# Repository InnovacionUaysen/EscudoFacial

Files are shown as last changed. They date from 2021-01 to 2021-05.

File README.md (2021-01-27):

# EscudoFacial
Escudo facial desarrollado por FabLab de la Universidad de Aysén
La informacion contenida en el manual adjunto debe respetarse para una correcta fabricación del escudo facial validado por el laboratorio Lictex de la Universidad de Santiago de Chile.
Este escudo facial esta registrado bajo las licencias Creative commons, 
Creative Commons Licence
EscudoFacial Uaysen by Universidad de Aysén is licensed under a Creative Commons Attribution-NoDerivatives 4.0 International License.
Based on a work at https://github.com/InnovacionUaysen/EscudoFacial.
<br /><span xmlns:dct="http://purl.org/dc/terms/" property="dct:title">EscudoFacial Uaysen</span> by <a xmlns:cc="http://creativecommons.org/ns#" href="https://github.com/InnovacionUaysen" property="cc:attributionName" rel="cc:attributionURL">Universidad de Aysén</a> is licensed under a <a rel="license" href="http://creativecommons.org/licenses/by-nd/4.0/">Creative Commons Attribution-NoDerivatives 4.0 International License</a>.<br />Based on a work at <a xmlns:dct="http://purl.org/dc/terms/" href="https://github.com/InnovacionUaysen/EscudoFacial" rel="dct:source">https://github.com/InnovacionUaysen/EscudoFacial</a>.

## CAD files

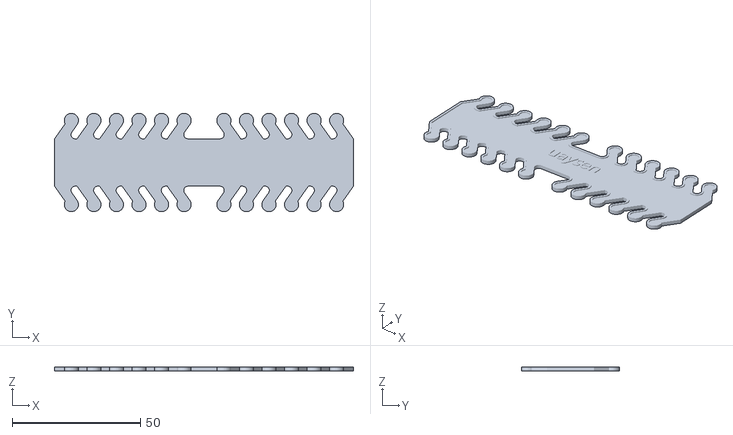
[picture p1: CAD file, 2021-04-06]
salvaorejas 2.stl
116.6 x 38.4 x 1.50

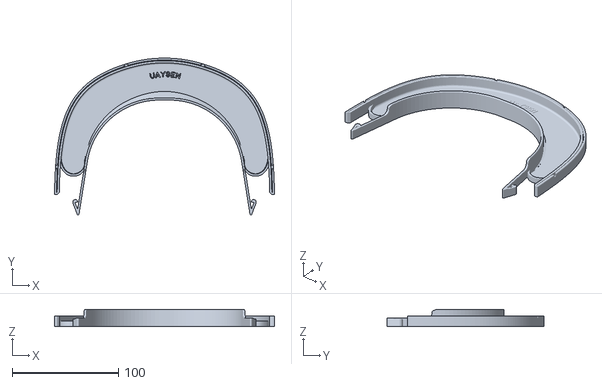
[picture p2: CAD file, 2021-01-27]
Escudo Facial Uaysen 1.7.stl
206.8 x 147.4 x 16.0

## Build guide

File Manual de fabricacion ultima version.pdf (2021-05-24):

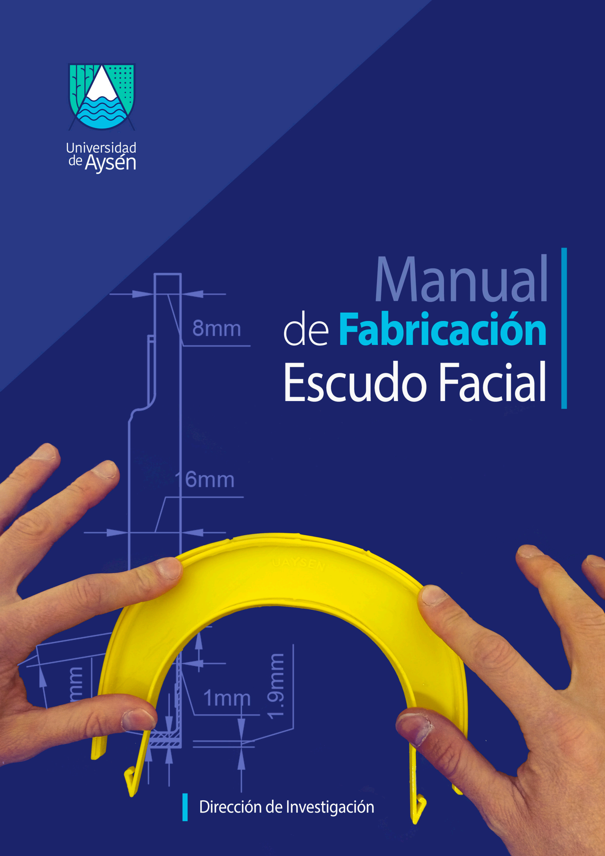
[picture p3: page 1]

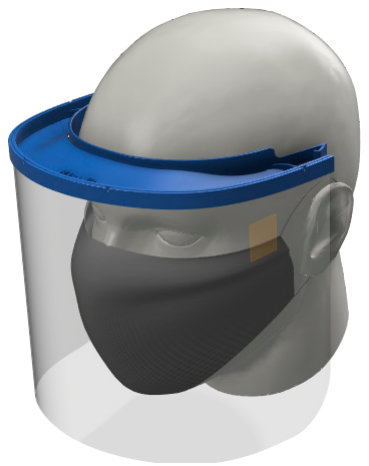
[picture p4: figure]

2 / Manual de Fabricación de Escudo Facial de la Universidad de Aysén

### 1. RESUMEN

Bajo el financiamiento del Ministerio de Ciencias y Corfo, la Universidad de Aysén a través del laboratorio FABLAB hace el esfuerzo para el desarrollo de diseño y fabricación de un escudo facial impreso en 3D. Las características únicas de este diseño EPP han sido optimizadas, cumpliendo con ensayos técnicos resueltos por un laboratorio externo para el uso en este servicio.

Este manual tiene como objetivo general entregar toda información útil sobre la fabricación y ensamble del escudo facial impreso en 3D. De igual manera será claro respecto a la información de calidad y procedimientos así como buenas prácticas de fabricación. Además ha sido creado para proveedores de productos impresos en 3d para que puedan imprimir correctamente este diseño y así mantener las características y funcionalidad que han sido previamente probadas en los ensayos técnicos.

Los escudos faciales que no se ajusten a la calidad descrita en este manual de fabricación no serán considerados como Escudos Faciales de la Universidad de Aysén.

### 2 DEFINICIONES

# Manual de Fabricación de Escudo Facial

1

Fabricante: Persona o empresa que produce bienes tangibles para su distribución y comercialización.

Elemento de Protección Personal: De acuerdo a la legislación vigente se entiende por elemento de protección personal (EPP) “todo equipo, aparato o dispositivo especialmente proyectado y fabricado para preservar el cuerpo humano, en todo o en parte, de riesgos específicos de accidentes del trabajo o enfermedades profesionales” (Art. 1° del Decreto Supremo N°173 , de 1982, del Ministerio de Salud).

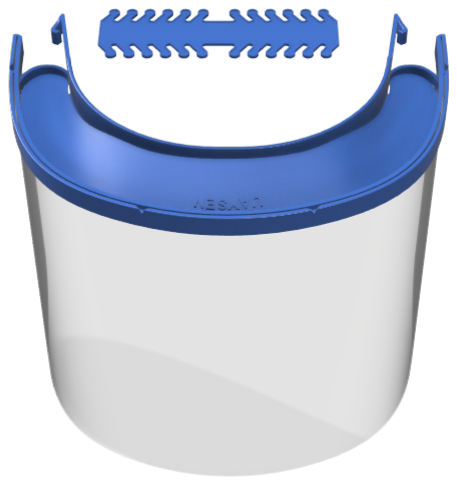
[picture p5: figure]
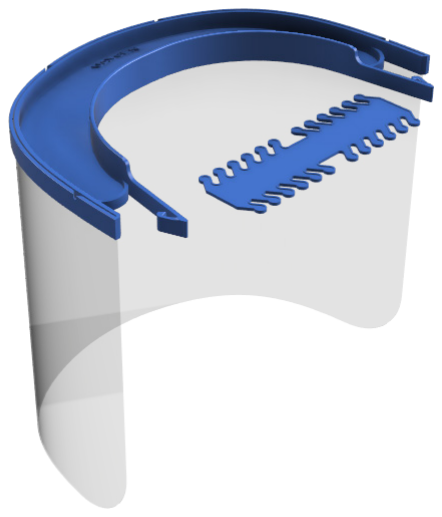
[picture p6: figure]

Manual de Fabricación de Escudo Facial de la Universidad de Aysén /3

DESCRIPCIÓN DEL ESCUDO FACIAL DE LA UNIVERSIDAD DE AYSÉN

El escudo facial desarrollado, consta de un soporte impreso en 3D que sostiene la pantalla que es una lámina de policarbonato de 0,7mm troquelada para calzar en el soporte anteriormente mencionado, este escudo facial es de carácter reutilizable.

Descripción técnica del EPP:

1. Pantalla hecha de una lámina de policarbonato transparente de 0,7mm
2. Banda Anular de Caucho para ajuste del EPP-EF
3. Soporte de Polímero Termoplástico Biodegradable, Ácido Polilácticos, para impresión 3D (PLA)
4. Salva oreja de PLA

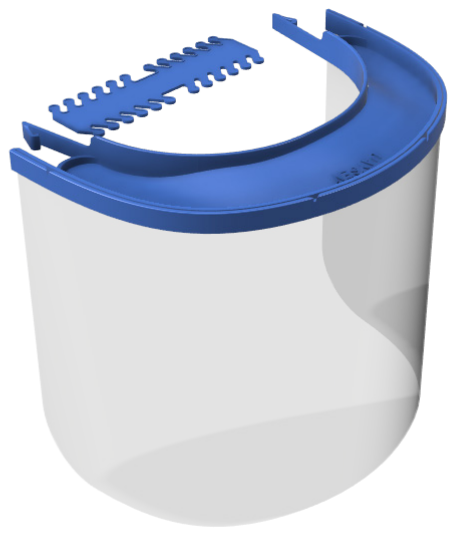
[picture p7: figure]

Imágenes de representación digital del escudo facial de la Universidad de Aysén.

INTRODUCCIÓN

El quiebre de stock mundial generado por el Covid-19 incrementó el costo de los EPP críticamente en el mundo, generando una escasez grave en la región de Aysén. Para enfrentar de manera preparada nuevos brotes o periodos críticos en la región es oportuno estar preparados a nivel local con los insumos y metodologías en la fabricación de EPP.

La fabricación digital da la oportunidad no solo a “makers” o usuarios experimentados en impresión 3D sino además a nuevos emprendedores que buscan el desarrollo de alternativas de productos innovadores así como EPP impresos.

3

4

Los objetivos específicos de este manual son los siguientes:

### 3.1 Describir y recomendar variables críticas de

fabricación del soporte del escudo facial impreso en 3D.

### 3.2 Orientar al fabricante sobre el post proceso con

agua caliente para correcta posición de superficie cobertora y ensamble completo del escudo facial.

### 3.3 Describir acabadamente la calidad del escudo facial

bajo los estándares establecidos por la Universidad de Aysén.

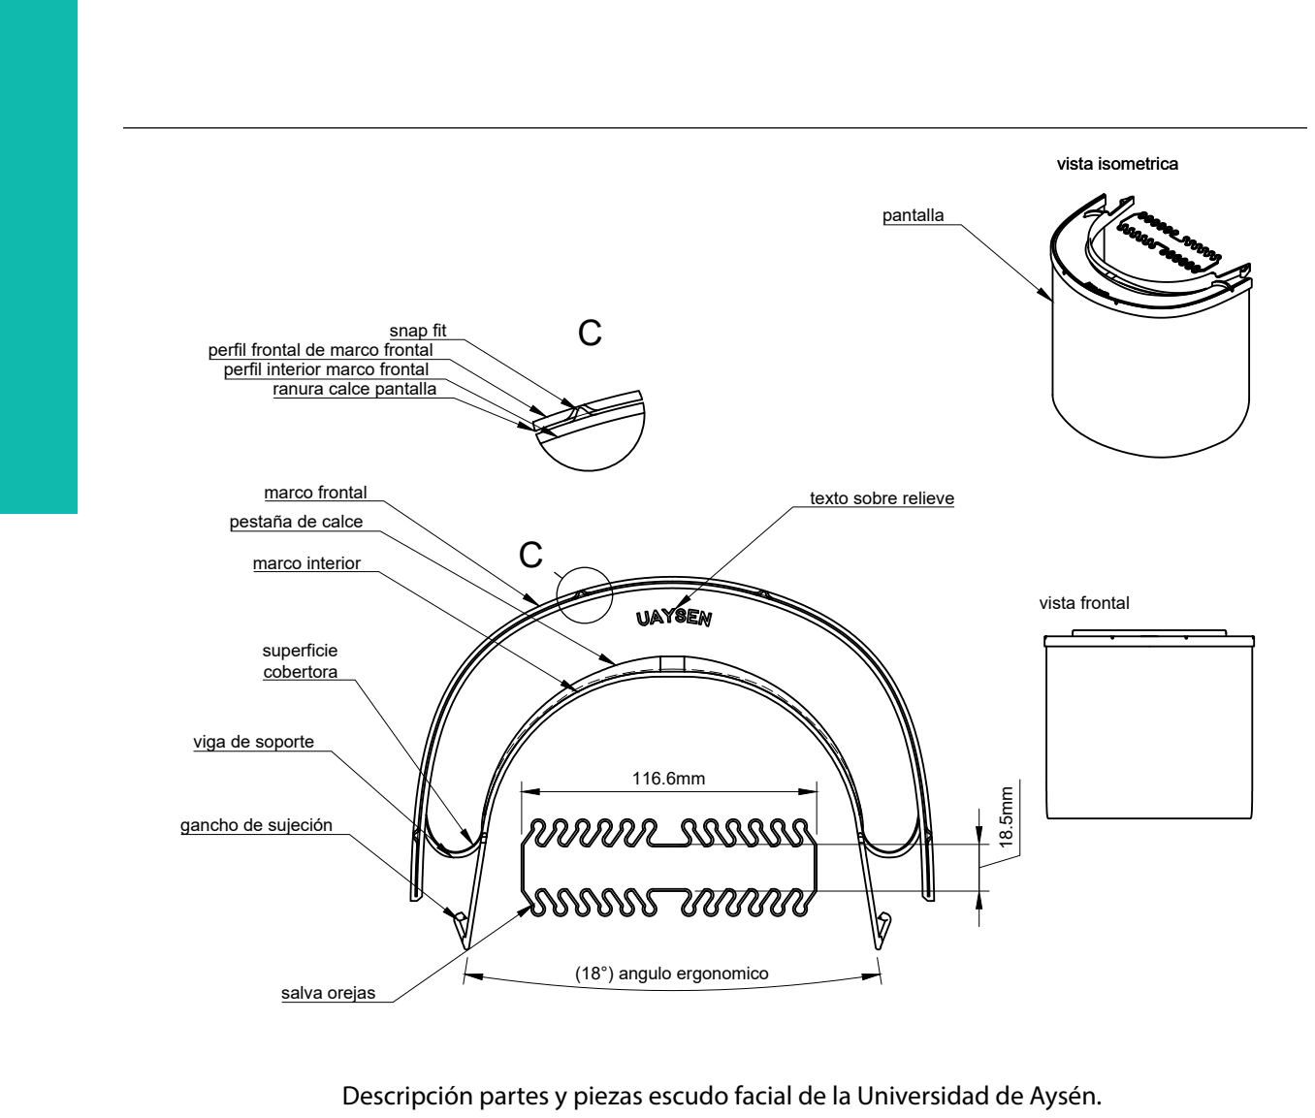
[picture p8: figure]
superficie cobertora; marco frontal; perfil frontal de marco frontal; snap fit; perfil interior marco frontal ranura calce pantalla; pestaña de calce; marco interior; gancho de sujeción; viga de soporte; (18°) angulo ergonomico; texto sobre relieve; salva orejas; pantalla; vista isometrica; vista frontal
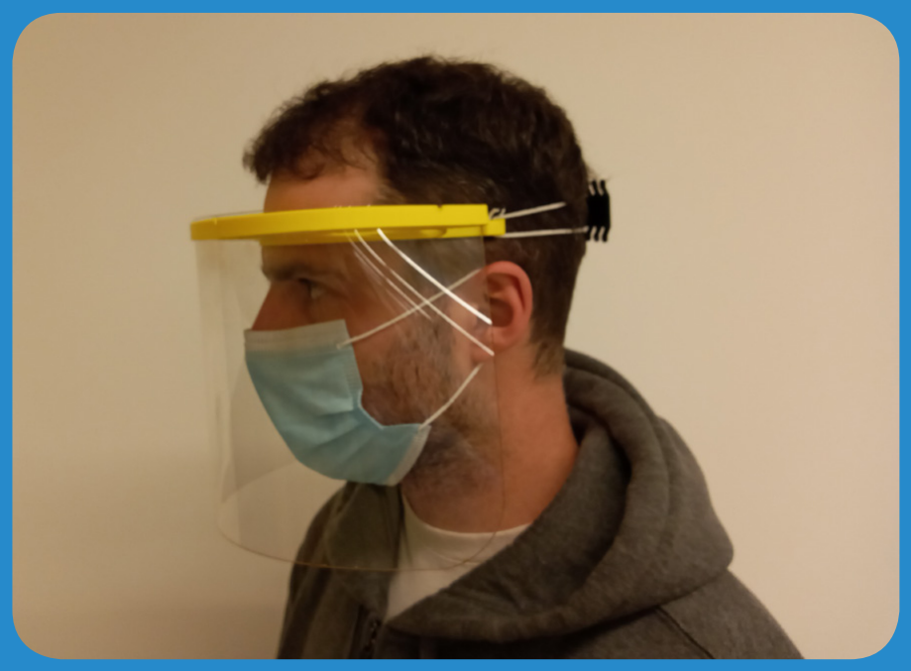
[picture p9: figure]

4 / Manual de Fabricación de Escudo Facial de la Universidad de Aysén

El escudo facial está pensado para durar al menos un mes con la correcta manipulación especificado por el protocolo de uso desarrollado por la universidad.

Por otro lado, en términos de su fabricación es un escudo facial que se puede imprimir en la mayoría de las impresoras 3d disponibles en el mercado, optimizando el tiempo de impresión sin perjudicar la flexibilidad del soporte, esto permite asegurar una producción más rápida y no perjudicar la comodidad del usuario.

Descripción partes y piezas escudo facial de la Universidad de Aysén.

Manual de Fabricación de Escudo Facial de la Universidad de Aysén /5

REQUERIMIENTO ESPECÍFICOS DE FABRICACIÓN

La fabricación y ensamblado se resume en los siguientes pasos:

1. Impresión 3D de la estructura general y salva oreja.
2. Post proceso con agua caliente para la correcta posición de superficie cobertora.
3. Corte de lámina de policarbonato de 0,7mm.
4. Ensamblado de pantalla y soporte del escudo.
5. Incorporación de elásticos.

5.1 Impresión 3D de la estructura general y salva oreja. Requerimientos de fabricación en impresión en 3D.

## - PLA - 20% Relleno - Tº de Extrusión: 200 Cº - Altura de Capa: menor a 0.8 mm - Grosor de Pared: 0.4 mm - Uso de Retracción - Tº Placa de Impresión: 60 Cº - No uso de soporte para la impresión

## IMPORTANTE

5

Cada fabricante debe respetar los parámetros de fabricación que a continuación serán descritos para sostener la calidad y certificación que este modelo posee. El uso de software tales como CURA son recomendados para la verificación de los parámetros de diseño establecidos más adelante en este manual.

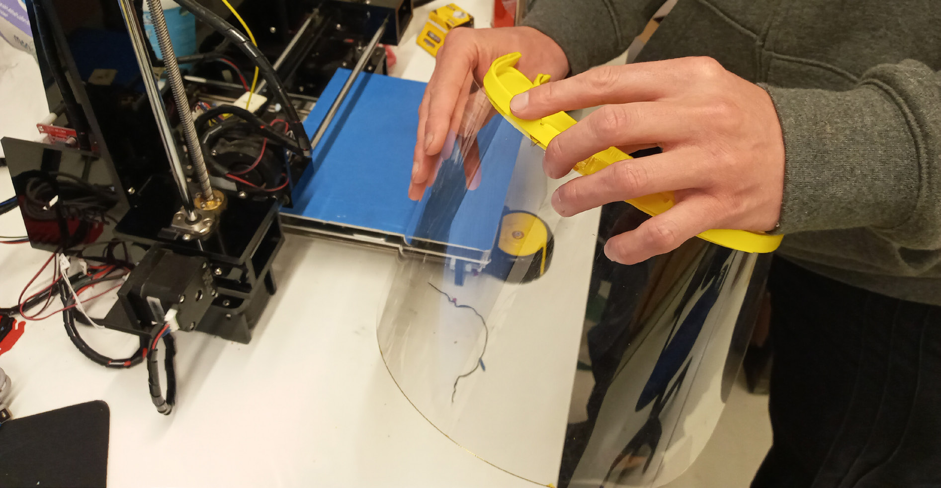
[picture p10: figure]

6 / Manual de Fabricación de Escudo Facial de la Universidad de Aysén

- Tipo de material:
El soporte del escudo facial está hecho Polímero Termoplástico Biodegradable, Ácido PoliLácticos, para impresión 3D (PLA) y el fabricante está obligado a usar este material en la fabricación.
- Porcentaje de relleno:
El fabricante estará obligado a fabricar o imprimir en 3D un soporte del escudo con un mínimo de relleno de un 20%. Este parámetro ha sido optimizado para luego ser evaluado y aceptado en la validación externa.
- Temperatura de extrusión:
Se recomienda una temperatura de extrusión de 200 Cº para el trabajo con PLA o temperatura recomendada por el fabricante del filamento a usar.
- Altura de capas de impresión:
Se recomienda trabajar con una altura de capas no superior a 0.8 mm
- Grosor de la pared:
Se recomienda un grosor de pared 0.4mm, dependiendo del tamaño de la boquilla a usar.
- Retracción:
Se recomienda el uso de retracción como parámetro de impresión 3D.
- Adherencia a placa de impresión:
Dado que la superficie del Escudo Facial que se adhiere a la placa es amplia y se espera sea lisa, se recomienda no usar ningún tipo de soporte de adherencia a la placa de impresión, esto permite optimizar el espacio usado dentro de la superficie disponible para imprimir, al mismo tiempo permite que el escudo quepa en impresoras de 20x20cm de área de impresión.
- Temperatura de placa de impresión:
Se recomienda una temperatura de 60 Cº
- Soporte:
Se recomienda el NO usar soporte para la impresión como una buena práctica y cumplir con una superficie lisa.

Manual de Fabricación de Escudo Facial de la Universidad de Aysén /7

Control de Calidad

Luego de imprimir el soporte del escudo facial se debe verificar la calidad de impresión a través de una inspección visual de deformaciones o fallas de impresión que pueden surgir por variaciones del entorno o mecánicas de la impresora.

Es recomendable realizar una prueba manual y mecánica del soporte para verificar resistencia, elasticidad y plegado de capas.

Todas las medidas descritas en la imagen a continuación deben reflejarse en el modelo impreso en 3D para que corresponda a la calidad del escudo facial desarrollado por la Universidad de Aysén.

206.8mm

146.5mm

Se recomienda imprimir el salva oreja como el soporte del escudo facial juntos, para el ahorro de tiempo (ver imagen). Los archivos de estos diseños, es decir soporte y salva orejas serán proporcionados por el FABLAB de la Universidad de Aysén.

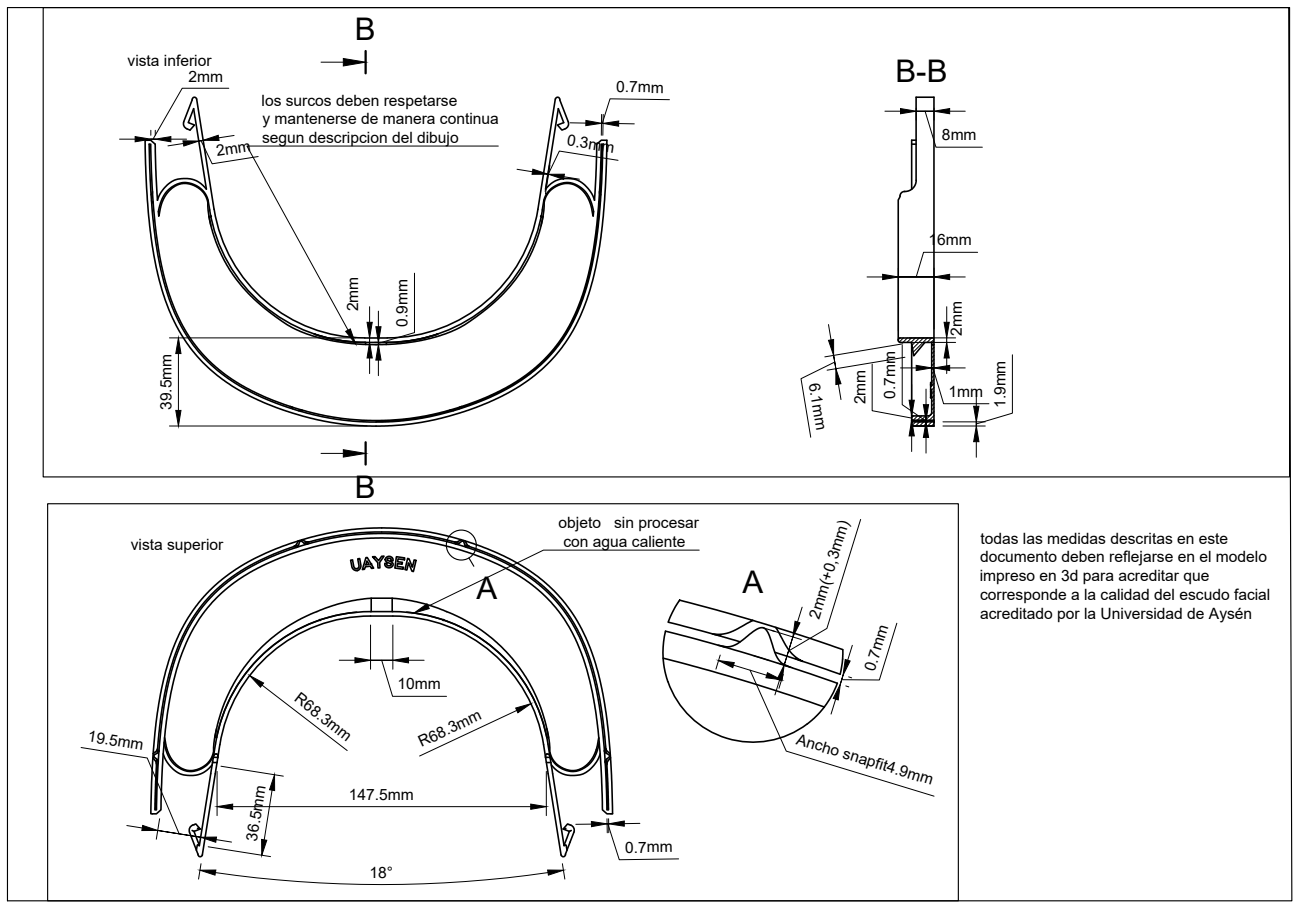
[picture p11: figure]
vista superior; vista inferior; objeto sin procesar con agua caliente; los surcos deben respetarse y mantenerse de manera continua segun descripcion del dibujo; todas las medidas descritas en este documento deben reflejarse en el modelo impreso en 3d para acreditar que; acreditado por la Universidad de Aysén; Ancho snapfit4.9mm

8 / Manual de Fabricación de Escudo Facial de la Universidad de Aysén

5.2 Post proceso con agua caliente para la correcta posición de la superficie cobertora.

Cada fabricante deberá exponer la superior del soporte del escudo facial una vez impreso a un shock térmico con agua caliente (60-80*C aprox) para moldear hasta su forma definitiva. Los siguientes pasos para un correcto moldeado es descrito y apoyado con imágenes:

corresponde a la calidad del escudo facial

1. Posicionar la superficie cobertora sobre la pestaña de calce.
2. Mojar sólo la superficie plana de la superficie cobertora con agua caliente (60-80 C° aprox).
3. Aplastar el marco de calce hacia abajo en una superficie plana con cuidado de no deformar la estructura general hasta que se enfríe el soporte.
4. Verificar ángulo de inclinación de las caras lisas para la correcta posición.

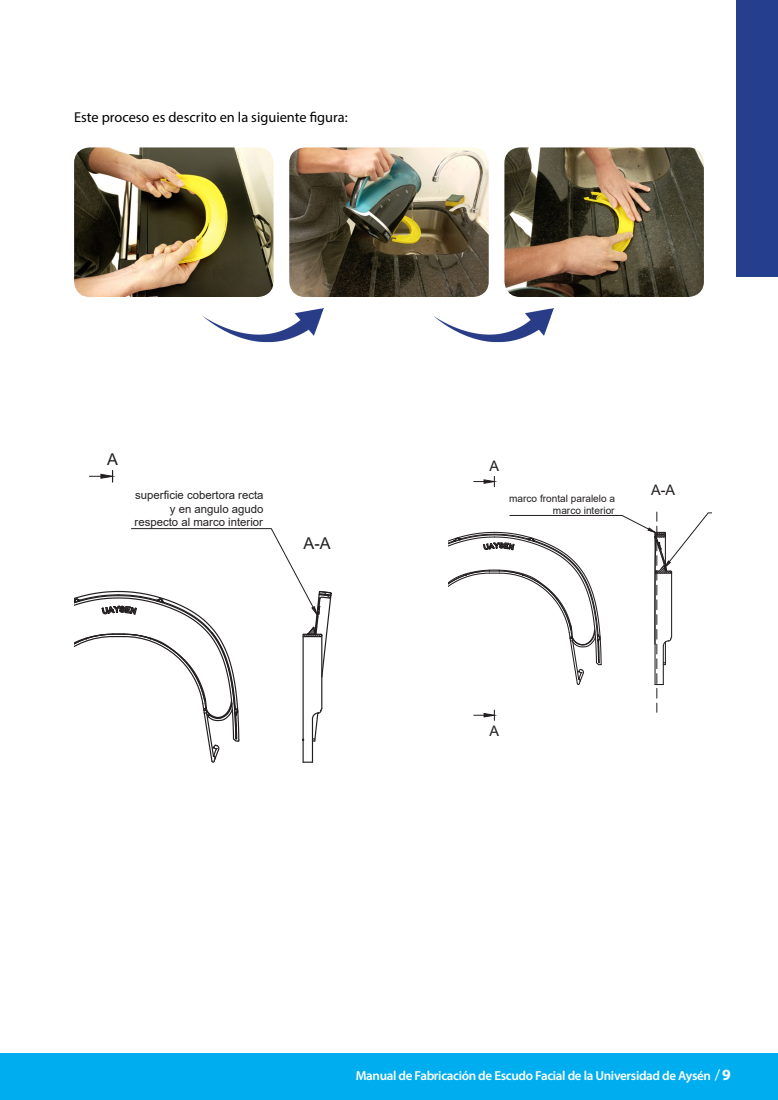
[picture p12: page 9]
marco interior

Este proceso es descrito en la siguiente figura:

superficie cobertora recta
y en angulo agudo
respecto al marco interior

marco frontal paralelo a

Manual de Fabricación de Escudo Facial de la Universidad de Aysén /9

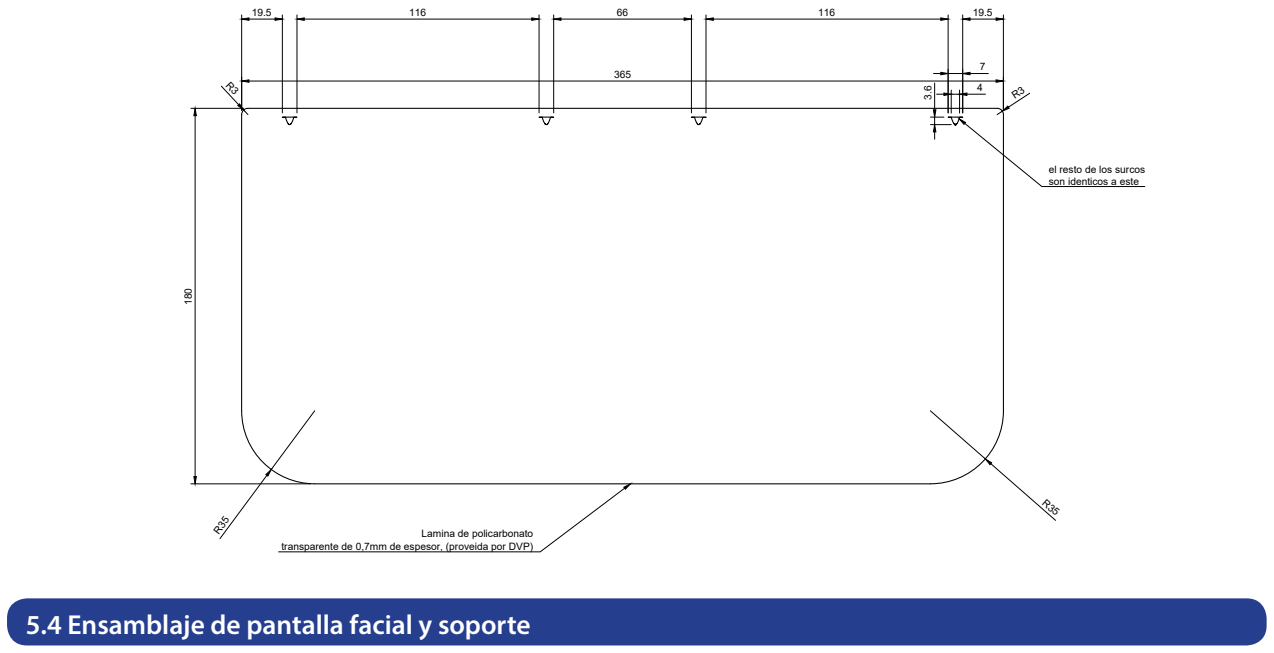
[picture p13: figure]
el resto de los surcos son identicos a este; Lamina de policarbonato
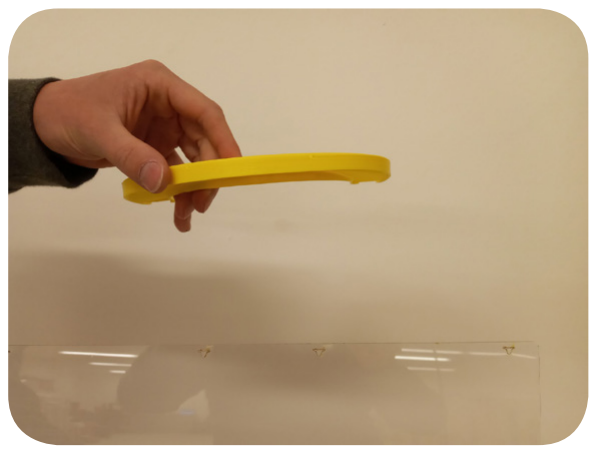
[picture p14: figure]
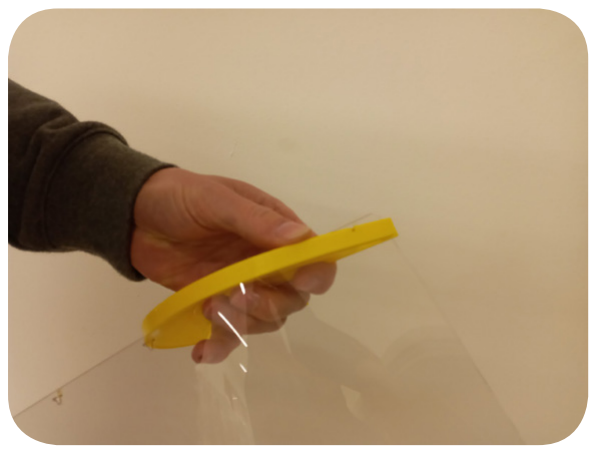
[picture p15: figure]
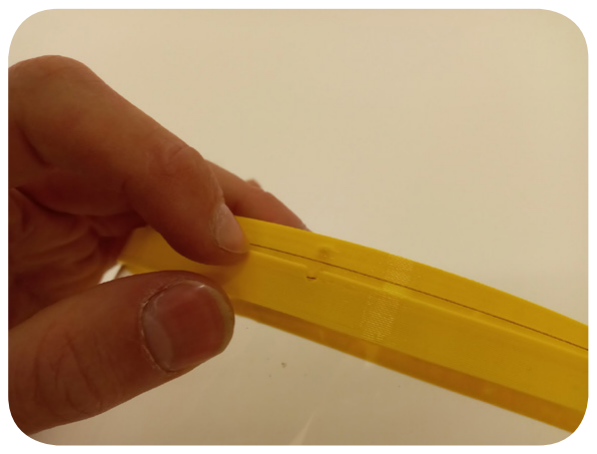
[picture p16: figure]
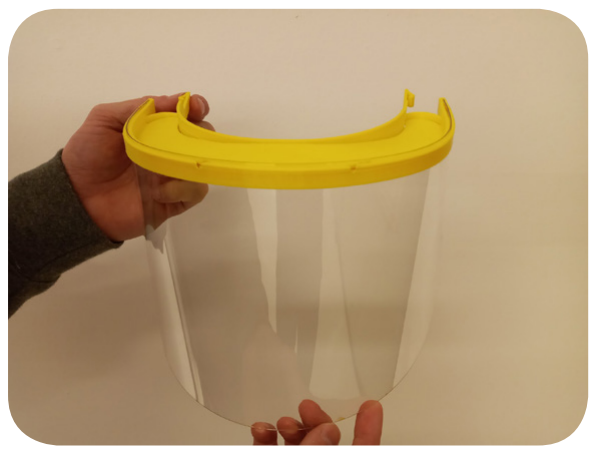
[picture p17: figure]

10 / Manual de Fabricación de Escudo Facial de la Universidad de Aysén

5.3 Corte de lámina de policarbonato de 0,7 mm.

### 5.4 Ensamblaje de pantalla facial y soporte

Una vez impreso el soporte y el control de calidad ha sido aplicado, se procede al ensamblaje del soporte y pantalla de policarbonato. Los seguros o “Snapfit” del soporte deben coincidir con los orificios de la pantalla para anclar ambas estructuras y dar firmeza al escudo completo.

transparente de 0,7mm de espesor, (proveida por DVP)

Plano tecnico de "Pantalla" Escudo facial

La pantalla está hecha de una lámina de policarbonato transparente de 0.7 mm la cual será cortada por un proveedor de troquelado y estará disponible a los fabricantes del escudo facial.

Es responsabilidad del fabricante del escudo facial ensamblar las partes del escudo facial para la entrega del producto terminado al demandante.

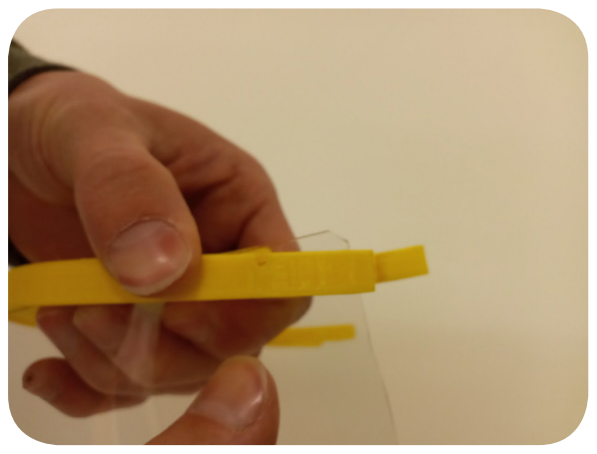
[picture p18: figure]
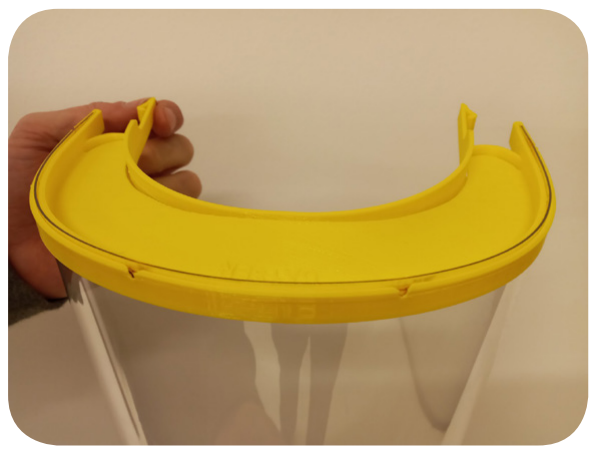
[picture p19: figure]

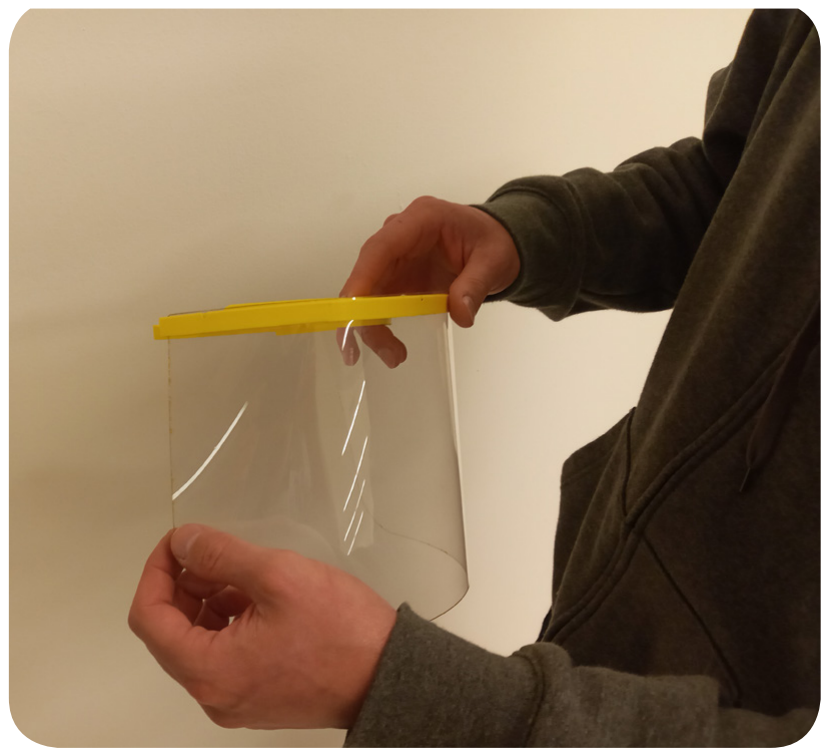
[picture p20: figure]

Manual de Fabricación de Escudo Facial de la Universidad de Aysén /11

CALIDAD

Este manual está diseñado para que el fabricante siga ciertos criterios de impresión para lograr mantener la calidad de un producto o diseño que ha sido validado por el Laboratorio Lictex. Es importante mantener no solo el procedimiento descrito en este manual, sino además proceder con buenas prácticas de impresión para finalmente el profesional de salud pueda usarlo correctamente. ¹,2,3,4,5.

### 6 CALIDAD

1. MINSAL 2017. Reglamento sobre elementos de protección personal de uso laboral. https://www.minsal.cl/wp-content/uploads/2017/11/Reglamento-EPP-final-para-consulta-p% C3%BAblica2017.pdf
2. Pasos para poner y sacar el Equipo de Protección Personal, del Ministerio de Salud. http://www.colegiomedico.cl/wp-content/uploads/2020/03/EPP.pdf
3. Recomendaciones para el uso de Elementos de Protección Personal (EPP) para trabajadores de la salud, elaborado por el Colegio Médico de Chile y la Sociedad Chilena de Infectología. http://www.colegiomedico.cl/wp-content/uploads/2020/03/recomendaciones-EPP-2.pdf
4. Circular C 37 Nº 01 de la Subsecretaría de Redes Asistenciales: Protocolo de uso de equipos de
protección personal en la prevención de transmisión COVID19. http://www.colegiomedico.cl/wp-content/uploads/2020/03/PROTOCOLO-DE-USO-DE-EQUIPOS-DE-PROTEC-CI%C3%93N-PERSONAL-EN-LA-PREVENCI%C3%93N-DE-TRANSMISI%C3%93N-COVID19.pdf
5. Requerimientos para uso de equipos de protección personal (EPP) para el nuevo coronavirus (2019-nCoV) en establecimientos de salud, de la Organización Mundial de la Salud. http://www.colegiomedico.cl/wp-content/uploads/2020/02/requirements-PPE-coronavirus-2020-02-07-spa.pdf

### 7 BIBLIOGRAFIA

### 8 CONTACTO

Jose Aldunate | jose.aldunate@uaysen.cl

12 / Manual de Fabricación de Escudo Facial de la Universidad de Aysén

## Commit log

2021-05-24 Add files via upload
    Manual de fabricación que debe ser respetado al momento de fabricar
2021-05-24 Add files via upload
    Manual de fabricación y condiciones mínimas a considerar
